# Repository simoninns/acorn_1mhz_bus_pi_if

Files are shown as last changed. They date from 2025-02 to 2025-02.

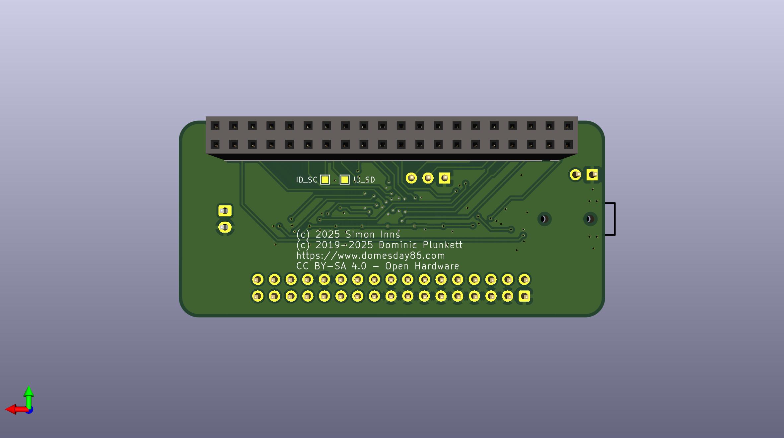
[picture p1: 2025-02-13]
docs/Acorn_1Mhz_bus_PiZero_interface_back.jpg

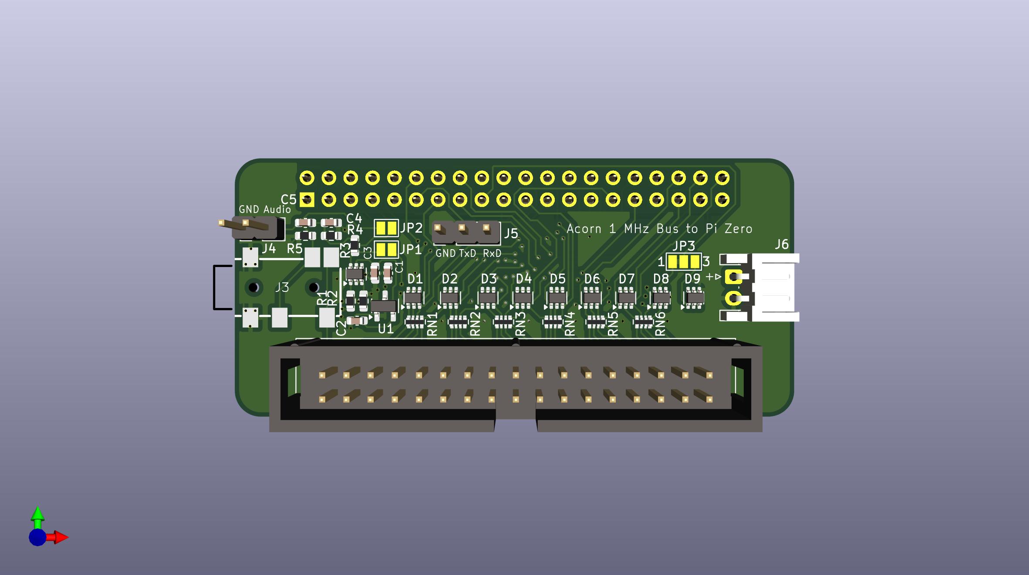
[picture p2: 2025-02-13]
docs/Acorn_1Mhz_bus_PiZero_interface_front.jpg

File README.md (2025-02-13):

# Overview
This project provides a Pi Zero hat which allows a Raspberry Pi to be connected to a BBC Micro or Master via the 1 MHz bus port.  The hat is compatible with all versions of the Raspberry Pi (with 40 pin GPIO headers)

Since the BBC Micro is 5Vs and the Pi is 3.3Vs bi-directional level shifting is required.  In addition, the board provides an active audio buffer to allow the Pi Zero to output audio via the GPIO header.  Audio is routed into the BBC Micro if the audio jack isn't required.

# Production
Production files for JLCPCB.com are included for both the PCB and component assembly.  A custom DRC is also included that checks the project files against JLC's production rules.  Production files can be found in the repo:

https://github.com/simoninns/acorn_1mhz_bus_pi_if/tree/main/kicad/jlcpcb

# Use with Raspberry Pi 3B+
Some Raspberry Pi models will not boot due to leakage on the 3.3V rails - the project provides a jumper that can be set if you want to use on of the affected models.  JP3 pins 1 to 2 should be cut and a solder blob placed on 2-3.  Please see the schematic for details.

# Removal of active audio
To lower production cost the on-board LDO and buffer ICs can be omitted (as well as the audio jack).  Bridging JP1 and JP2 will bypass the active components and provide only a passive audio filter (this works fine but provides a poorer sound quality).

## Project status
This project is at first release.  Please read the wiki and see YouTube for consruction videos (detailed in the wiki also).

## Author
This project is designed and maintained by Simon Inns with help from Dominic Plunkett and Daniel Jameson.

## Software License (GPLv3)

    This is free software: you can redistribute it and/or modify
    it under the terms of the GNU General Public License as published by
    the Free Software Foundation, either version 3 of the License, or
    (at your option) any later version.

    Valiant Turtle 2 is distributed in the hope that it will be useful,
    but WITHOUT ANY WARRANTY; without even the implied warranty of
    MERCHANTABILITY or FITNESS FOR A PARTICULAR PURPOSE.  See the
    GNU General Public License for more details.

    You should have received a copy of the GNU General Public License
    along with this program.  If not, see <http://www.gnu.org/licenses/>.

## Hardware License (Creative Commons BY-SA 4.0)
Please see the following link for details: https://creativecommons.org/licenses/by-sa/4.0/

You are free to:

Share - copy and redistribute the material in any medium or format
Adapt - remix, transform, and build upon the material
for any purpose, even commercially.

This license is acceptable for Free Cultural Works.

The licensor cannot revoke these freedoms as long as you follow the license terms.

Under the following terms:

Attribution - You must give appropriate credit, provide a link to the license, and indicate if changes were made. You may do so in any reasonable manner, but not in any way that suggests the licensor endorses you or your use.

ShareAlike - If you remix, transform, or build upon the material, you must distribute your contributions under the same license as the original.

No additional restrictions - You may not apply legal terms or technological measures that legally restrict others from doing anything the license permits.

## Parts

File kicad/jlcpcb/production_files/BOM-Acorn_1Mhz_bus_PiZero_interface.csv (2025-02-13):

Comment | Designator | Footprint | LCSC | Quantity
100R | R1,R4 | R_0603_1608Metric | C105588 | 2
220R | R3 | R_0603_1608Metric | C107696 | 1
470R | R2 | R_0603_1608Metric | C114433 | 1
47uF | C5 | C_0603_1608Metric | C140782 | 1
1K8 | R5 | R_0603_1608Metric | C144686 | 1
100nF | C3,C4 | C_0603_1608Metric | C14663 | 2
MMBD4148TW | D1,D2,D3,D4,D5,D6,D7,D8,D9 | SOT-363_SC-70-6 | C157538 | 9
1uF | C1,C2 | C_0603_1608Metric | C15849 | 2
1MHz Bus | J1 | IDC-Header_2x17_P2.54mm_Vertical | C20920 | 1
Audio_Jack_3420 | J3 | PJ-3420-X-SMT | C319102 | 1
100R | RN1,RN2,RN3,RN4,RN5,RN6 | R_Array_Convex_4x0402 | C326873 | 6
Power In | J6 | JST_EH_S2B-EH_1x02_P2.50mm_Horizontal | C514173 | 1
NC7WZ16 | U2 | SOT-363_SC-70-6 | C5207819 | 1
XC6206P332MR | U1 | SOT-23-3 | C5446 | 1

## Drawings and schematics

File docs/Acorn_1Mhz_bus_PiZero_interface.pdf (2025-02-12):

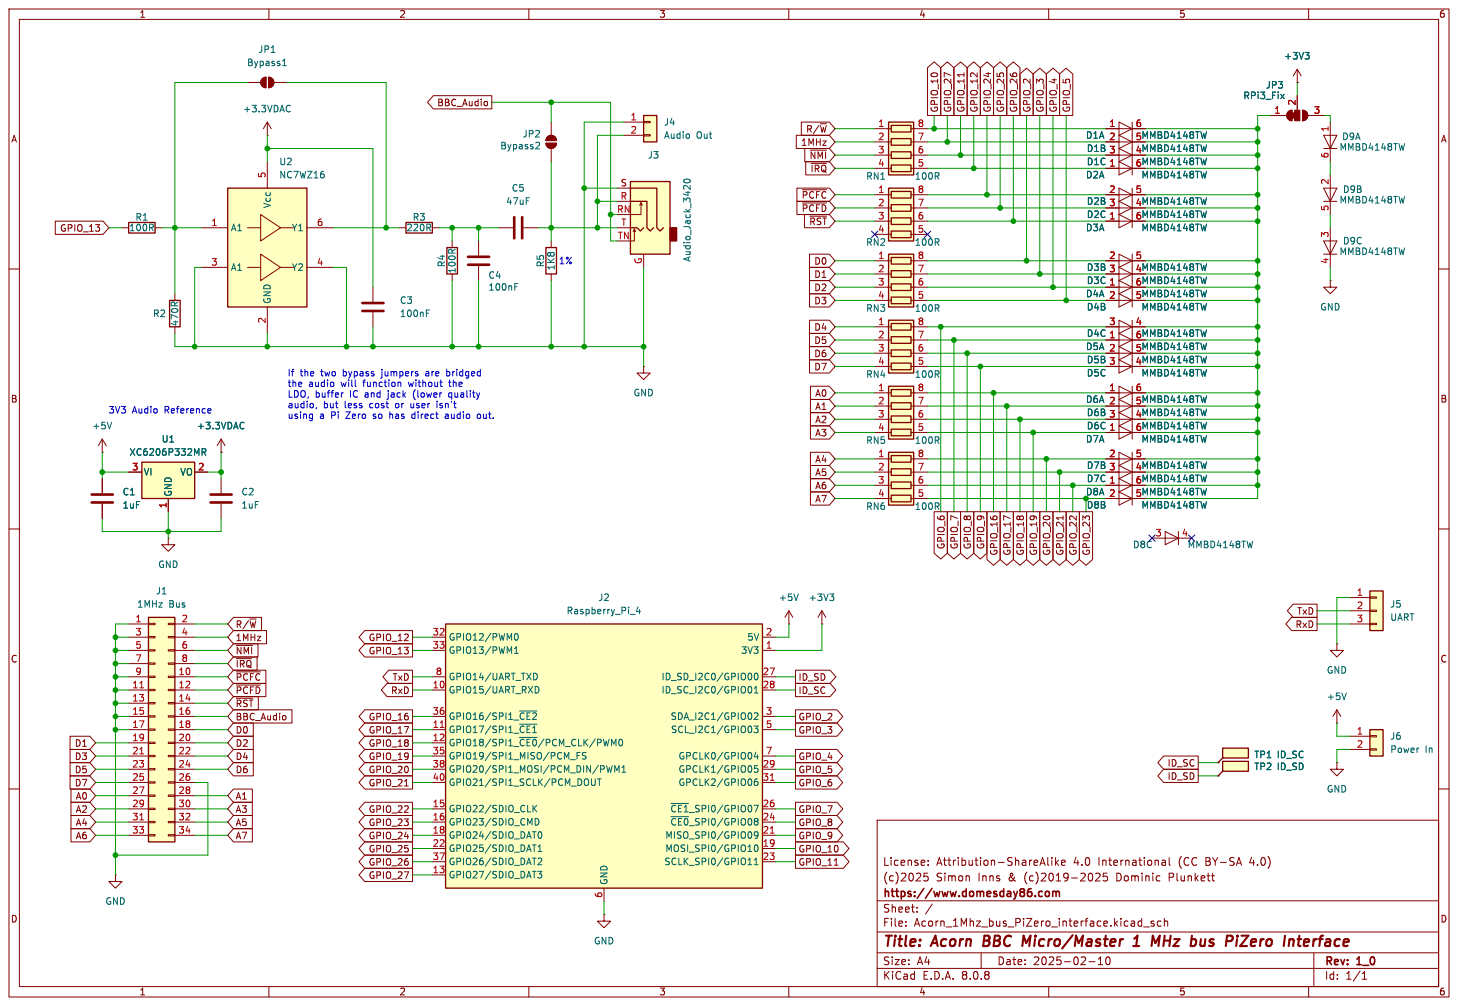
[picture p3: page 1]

If the two bypass jumpers are bridged

File: Acorn_1Mhz_bus_PiZero_interface.kicad_sch Sheet: / https://www.domesday86.com

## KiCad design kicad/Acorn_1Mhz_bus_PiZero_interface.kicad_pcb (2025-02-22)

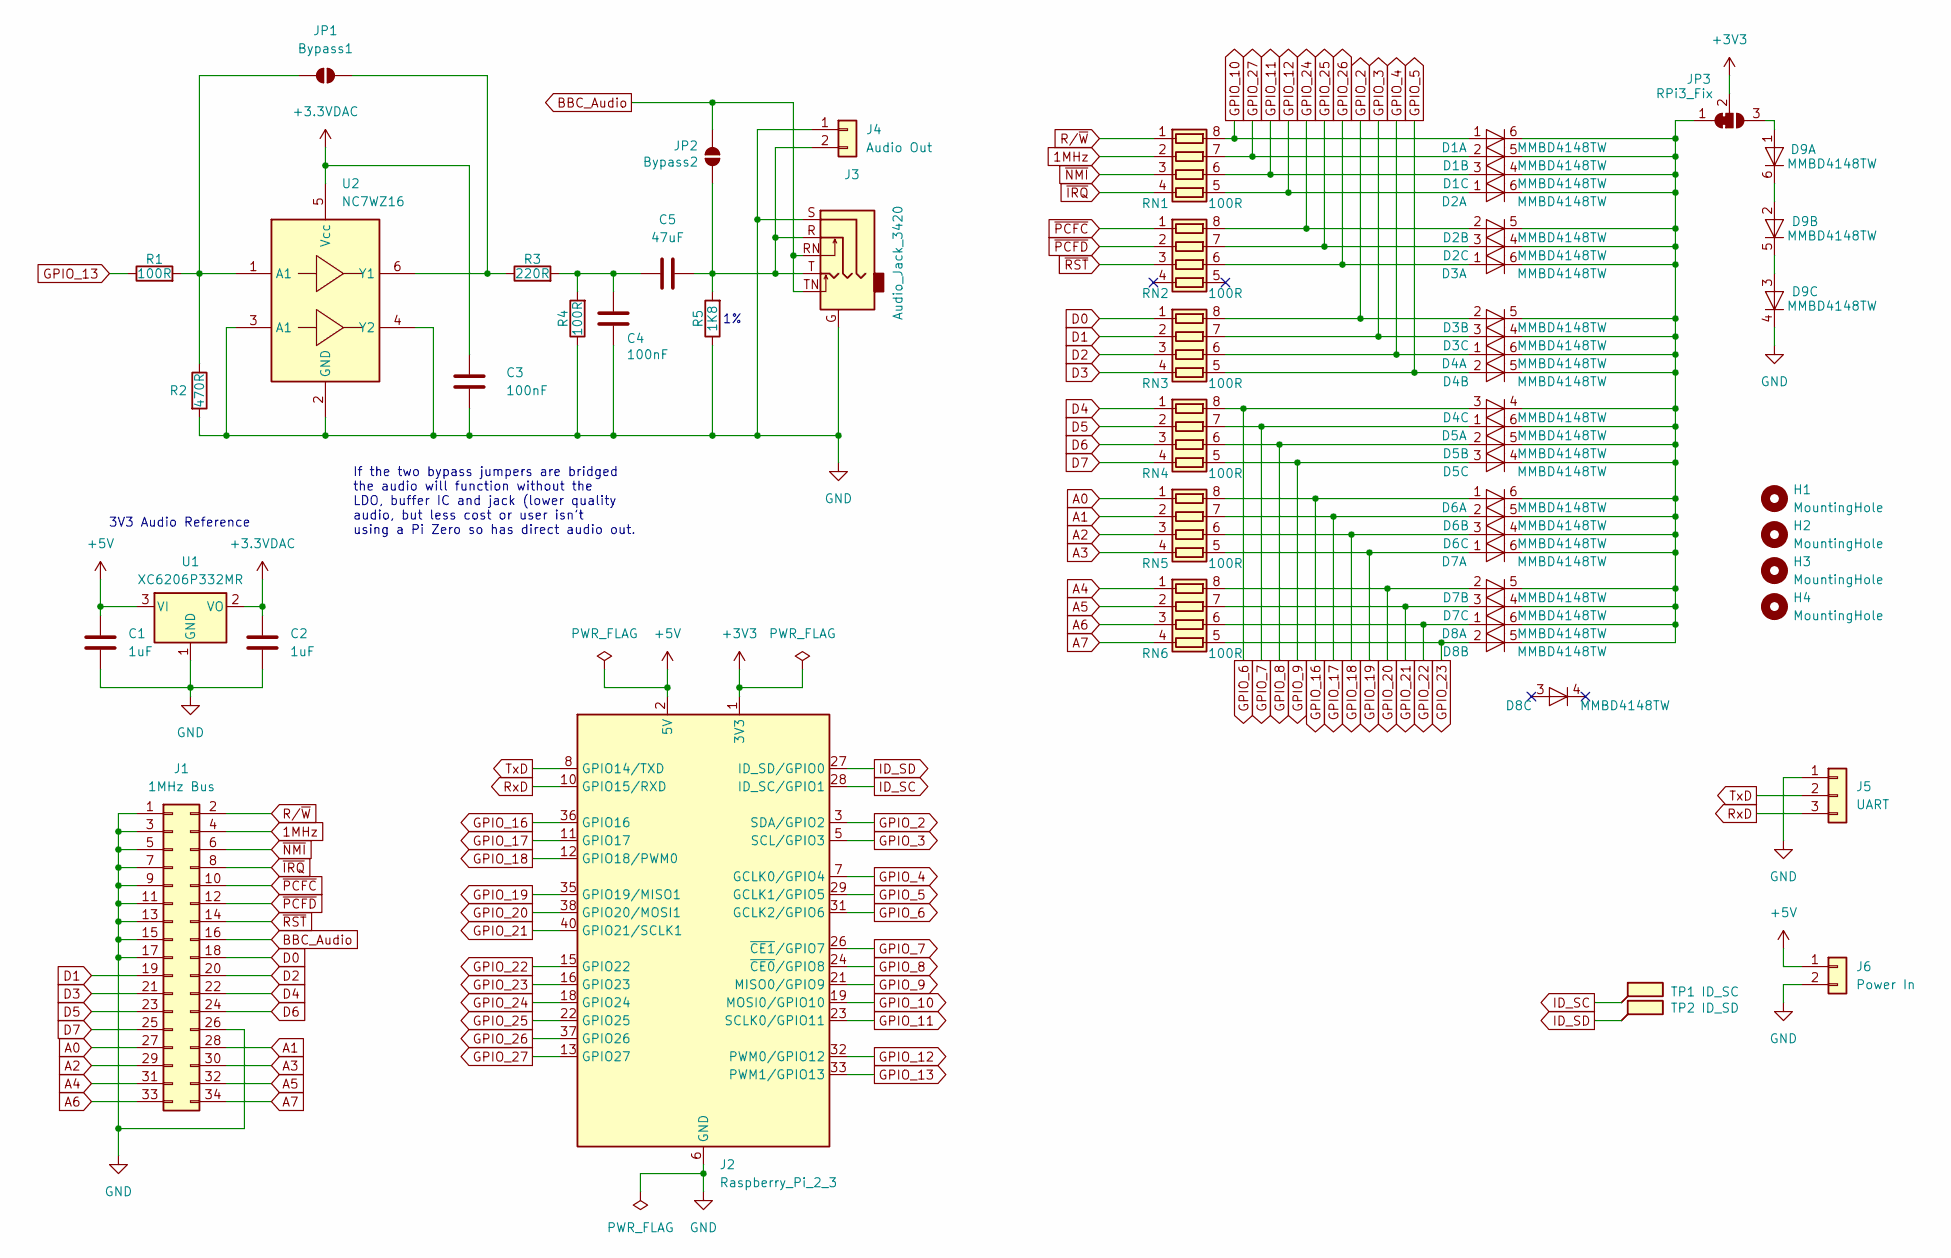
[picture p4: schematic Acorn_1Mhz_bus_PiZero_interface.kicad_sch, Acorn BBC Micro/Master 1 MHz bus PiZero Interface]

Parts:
C1, C2: 1uF; C_0603_1608Metric; LCSC C15849
C3, C4: 100nF; C_0603_1608Metric; LCSC C14663
C5: 47uF; C_0603_1608Metric; LCSC C140782
D1, D2, D3, D4, D5, D6, D7, D8, D9: MMBD4148TW; SOT-363_SC-70-6; LCSC C157538
H1, H2, H3, H4: MountingHole; MountingHole_2.7mm_M2.5_DIN965
J1: 1MHz Bus; IDC-Header_2x17_P2.54mm_Vertical; LCSC C20920
J2: Raspberry_Pi_2_3; PinSocket_2x20_P2.54mm_Vertical
J3: Audio_Jack_3420; PJ-3420-X-SMT; LCSC C319102
J4: Audio Out; PinHeader_1x02_P2.54mm_Vertical
J5: UART; PinHeader_1x03_P2.54mm_Vertical
J6: Power In; JST_EH_S2B-EH_1x02_P2.50mm_Horizontal; LCSC C514173
JP1: Bypass1; SolderJumper-2_P1.3mm_Open_Pad1.0x1.5mm
JP2: Bypass2; SolderJumper-2_P1.3mm_Open_Pad1.0x1.5mm
JP3: RPi3_Fix; SolderJumper-3_P1.3mm_Bridged12_Pad1.0x1.5mm_NumberLabels
R1, R4: 100R; R_0603_1608Metric; LCSC C105588
R2: 470R; R_0603_1608Metric; LCSC C114433
R3: 220R; R_0603_1608Metric; LCSC C107696
R5: 1K8; R_0603_1608Metric; LCSC C113298
RN1, RN2, RN3, RN4, RN5, RN6: 100R; R_Array_Convex_4x0402; LCSC C326873
TP1: ID_SC; TestPoint_Pad_1.0x1.0mm
TP2: ID_SD; TestPoint_Pad_1.0x1.0mm
U1: XC6206P332MR; SOT-23-3; LCSC C5446
U2: NC7WZ16; SOT-363_SC-70-6; LCSC C5207819

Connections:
1MHz: J1.4, RN1.2 (R2.1)
+3.3VDAC: C2.1, C3.1, U1.2 (VO), U2.5 (Vcc)
+3V3: J2.1 (3V3), J2.17 (3V3), JP3.2 (C)
+5V: C1.1, J2.2 (5V), J2.4 (5V), J6.1, U1.3 (VI)
A0: J1.27, RN5.1 (R1.1)
A1: J1.28, RN5.2 (R2.1)
A2: J1.29, RN5.3 (R3.1)
A3: J1.30, RN5.4 (R4.1)
A4: J1.31, RN6.1 (R1.1)
A5: J1.32, RN6.2 (R2.1)
A6: J1.33, RN6.3 (R3.1)
A7: J1.34, RN6.4 (R4.1)
BBC_Audio: J1.16, J3.RN, J3.TN, JP2.2 (B)
D0: J1.18, RN3.1 (R1.1)
D1: J1.19, RN3.2 (R2.1)
D2: J1.20, RN3.3 (R3.1)
D3: J1.21, RN3.4 (R4.1)
D4: J1.22, RN4.1 (R1.1)
D5: J1.23, RN4.2 (R2.1)
D6: J1.24, RN4.3 (R3.1)
D7: J1.25, RN4.4 (R4.1)
GND: C1.2, C2.2, C3.2, C4.2, D9.4 (K), J1.1, J1.3, J1.5, J1.7, J1.9, J1.11, J1.13, J1.15, J1.17, J1.26, J2.6 (GND), J2.9 (GND), J2.14 (GND), J2.20 (GND), J2.25 (GND), J2.30 (GND), J2.34 (GND), J2.39 (GND), J3.G, J3.S, J4.1, J5.1, J6.2, R2.2, R4.1, R5.1, U1.1 (GND), U2.2 (GND), U2.3 (A1), U2.4 (Y2)
GPIO_2: D3.2 (A), J2.3 (SDA/GPIO2), RN3.8 (R1.2)
GPIO_3: D3.3 (A), J2.5 (SCL/GPIO3), RN3.7 (R2.2)
GPIO_4: D4.1 (A), J2.7 (GCLK0/GPIO4), RN3.6 (R3.2)
GPIO_5: D4.2 (A), J2.29 (GCLK1/GPIO5), RN3.5 (R4.2)
GPIO_6: D4.3 (A), J2.31 (GCLK2/GPIO6), RN4.8 (R1.2)
GPIO_7: D5.1 (A), J2.26 (~CE1/GPIO7), RN4.7 (R2.2)
GPIO_8: D5.2 (A), J2.24 (~CE0/GPIO8), RN4.6 (R3.2)
GPIO_9: D5.3 (A), J2.21 (MISO0/GPIO9), RN4.5 (R4.2)
GPIO_10: D1.1 (A), J2.19 (MOSI0/GPIO10), RN1.8 (R1.2)
GPIO_11: D1.3 (A), J2.23 (SCLK0/GPIO11), RN1.6 (R3.2)
GPIO_12: D2.1 (A), J2.32 (PWM0/GPIO12), RN1.5 (R4.2)
GPIO_13: J2.33 (PWM1/GPIO13), R1.1
GPIO_16: D6.1 (A), J2.36 (GPIO16), RN5.8 (R1.2)
GPIO_17: D6.2 (A), J2.11 (GPIO17), RN5.7 (R2.2)
GPIO_18: D6.3 (A), J2.12 (GPIO18/PWM0), RN5.6 (R3.2)
GPIO_19: D7.1 (A), J2.35 (GPIO19/MISO1), RN5.5 (R4.2)
GPIO_20: D7.2 (A), J2.38 (GPIO20/MOSI1), RN6.8 (R1.2)
GPIO_21: D7.3 (A), J2.40 (GPIO21/SCLK1), RN6.7 (R2.2)
GPIO_22: D8.1 (A), J2.15 (GPIO22), RN6.6 (R3.2)
GPIO_23: D8.2 (A), J2.16 (GPIO23), RN6.5 (R4.2)
GPIO_24: D2.2 (A), J2.18 (GPIO24), RN2.8 (R1.2)
GPIO_25: D2.3 (A), J2.22 (GPIO25), RN2.7 (R2.2)
GPIO_26: D3.1 (A), J2.37 (GPIO26), RN2.6 (R3.2)
GPIO_27: D1.2 (A), J2.13 (GPIO27), RN1.7 (R2.2)
ID_SC: J2.28 (ID_SC/GPIO1), TP1.1
ID_SD: J2.27 (ID_SD/GPIO0), TP2.1
unnamed: C4.1, C5.1, R3.2, R4.2
unnamed: D1.4 (K), D1.5 (K), D1.6 (K), D2.4 (K), D2.5 (K), D2.6 (K), D3.4 (K), D3.5 (K), D3.6 (K), D4.4 (K), D4.5 (K), D4.6 (K), D5.4 (K), D5.5 (K), D5.6 (K), D6.4 (K), D6.5 (K), D6.6 (K), D7.4 (K), D7.5 (K), D7.6 (K), D8.5 (K), D8.6 (K), JP3.1 (A)
unnamed: D9.1 (A), JP3.3 (B)
unnamed: D9.2 (A), D9.6 (K)
unnamed: D9.3 (A), D9.5 (K)
unnamed: C5.2, J3.R, J3.T, J4.2, JP2.1 (A), R5.2
unnamed: JP1.1 (A), R1.2, R2.1, U2.1 (A1)
unnamed: JP1.2 (B), R3.1, U2.6 (Y1)
RxD: J2.10 (GPIO15/RXD), J5.3
R/~W: J1.2, RN1.1 (R1.1)
TxD: J2.8 (GPIO14/TXD), J5.2
~IRQ: J1.8, RN1.4 (R4.1)
~NMI: J1.6, RN1.3 (R3.1)
~PCFC: J1.10, RN2.1 (R1.1)
~PCFD: J1.12, RN2.2 (R2.1)
~RST: J1.14, RN2.3 (R3.1)

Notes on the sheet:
If the two bypass jumpers are bridged the audio will function without the LDO, buffer IC and jack (lower quality audio, but less cost or user isn't using a Pi Zero so has direct audio out.
3V3 Audio Reference

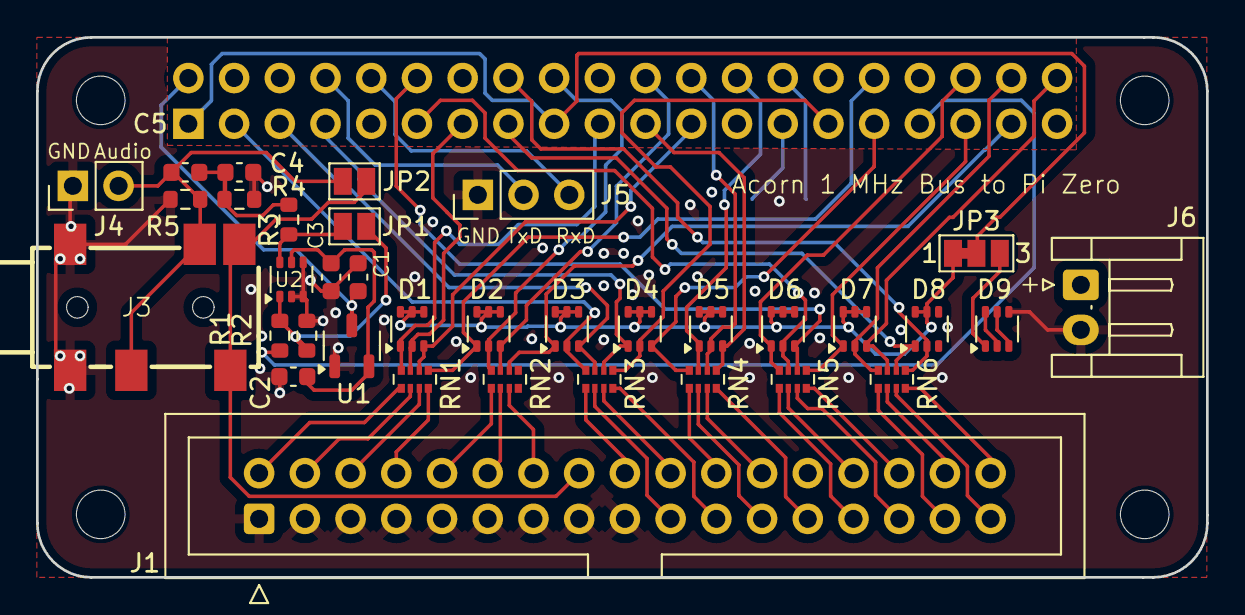
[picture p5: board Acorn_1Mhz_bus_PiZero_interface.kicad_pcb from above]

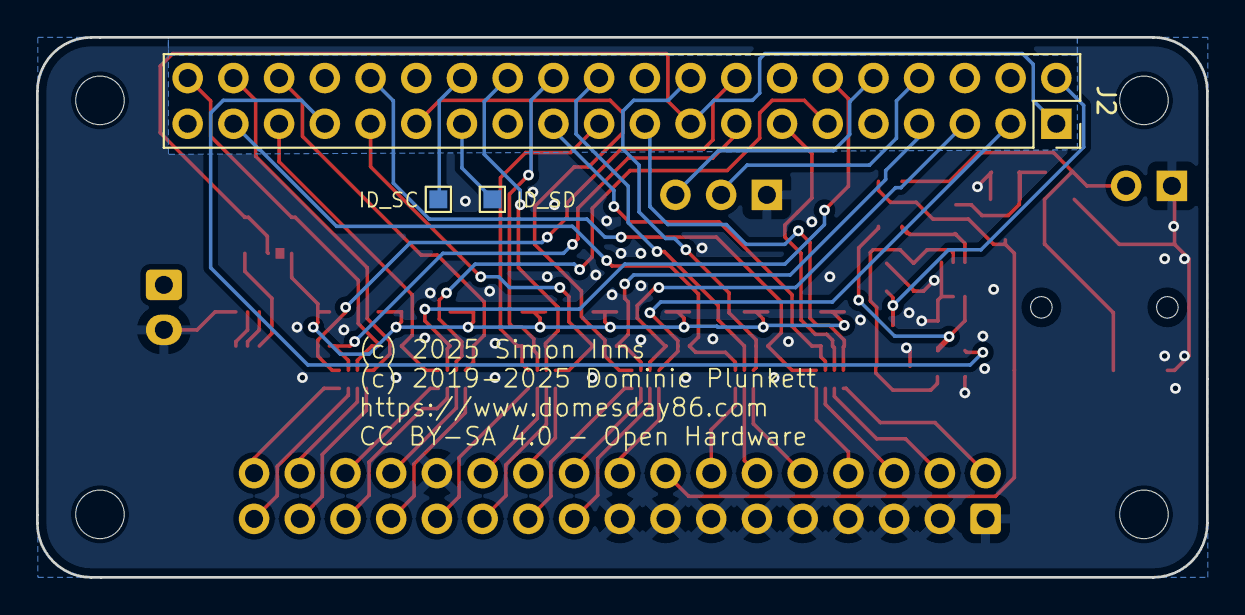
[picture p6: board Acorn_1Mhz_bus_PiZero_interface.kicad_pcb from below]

Board: 4 copper layers, 65.0 x 30.0 mm, 42 parts (3 on the bottom side), 64 nets.

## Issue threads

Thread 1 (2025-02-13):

Missing mounting holes in JLCPCB gerber images

simoninns, 2025-02-13:
In the gerber rendering on JLCPCB it looks like there are no mounting holes even though they were marked on the PCB.  It probably needs M2.5 mounting holes added to both the schematic and PCB files explicitly to ensure the finished board gets them.

This is not a big enough issue to prevent pre-release testing, so I'm raising this issue as a reminder to fix this before release.

simoninns, 2025-02-22:
Fixed in latest commit

Closed 2025-02-22.

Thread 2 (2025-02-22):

Internal speaker volume is low

simoninns, 2025-02-22:
The internal speaker volume is a little quiet due to the fact that the filter design is from the official Raspberry Pi schematics and only really suitable for the 3.5mm jack output.  It's probably not a really big issue since the internal speaker of the BBC Master is terrible quality anyway - but I'm raising this issue just to make a note.

The best way to solve it would probably be to add a small pre-amp on the audio output to the 1MHz bus connector.

simoninns, 2025-02-23:
I tested the amplitude of the audio output from the 3.5mm jack of a Pi 3B+ for comparison.  As expected, the amplitude of the level-shifter is the same (which it should be since it mirrors the audio buffer of the Pi).  So this issues is an enhancement rather than a bug-fix (and probably not worth solving).

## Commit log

2025-02-10 Basic KiCAD project with partial schematic - checking in before added Pi Zero sub-module
    [Acorn_1Mhz_bus_PiZero_interface.kicad_pcb, Acorn_1Mhz_bus_PiZero_interface.kicad_sch]
2025-02-10 Completed schematic ready for verification
    [Acorn_1Mhz_bus_PiZero_interface.kicad_sch]
2025-02-11 Completed schematic and added board file. Basic positioning is done but no routing.
    [Acorn_1Mhz_bus_PiZero_interface.kicad_pcb, Acorn_1Mhz_bus_PiZero_interface.kicad_sch]
2025-02-11 Got board outline and position of all components. Routing still missing.
    [Acorn_1Mhz_bus_PiZero_interface.kicad_pcb, Acorn_1Mhz_bus_PiZero_interface.kicad_sch]
2025-02-11 All PCB routing complete - just needs some copper fill
    [Acorn_1Mhz_bus_PiZero_interface.kicad_pcb]
2025-02-11 Flooded and ready for gerber generation - added renderings of front and back of PCB to docs
    [Acorn_1Mhz_bus_PiZero_interface.kicad_pcb]
2025-02-11 Changed board dimensions and redid the routing
    [Acorn_1Mhz_bus_PiZero_interface.kicad_pcb]
2025-02-11 Fixed some DRC warnings around silkscreen text sizes
    [Acorn_1Mhz_bus_PiZero_interface.kicad_pcb]
2025-02-11 Reversed polarity of the power connector. Added BoM spreadsheet with JLCPCB part numbers for assembly
    [Acorn_1Mhz_bus_PiZero_interface.kicad_pcb, Acorn_1Mhz_bus_PiZero_interface.kicad_sch, JLCPCB_BoM.ods]
2025-02-12 Added audio in/out test pads
    [Acorn_1Mhz_bus_PiZero_interface.kicad_pcb, Acorn_1Mhz_bus_PiZero_interface.kicad_sch]
2025-02-12 New schematic design with active audio buffering - schematic not updated
    [Acorn_1Mhz_bus_PiZero_interface.kicad_sch]
2025-02-12 New design for audio - added footprints (including SMD audio jack)
    [Acorn_1Mhz_bus_PiZero_interface.kicad_pcb, Acorn_1Mhz_bus_PiZero_interface.kicad_sch]
2025-02-12 Basic layout complete needs routing
    [Acorn_1Mhz_bus_PiZero_interface.kicad_pcb, Acorn_1Mhz_bus_PiZero_interface.kicad_sch]
2025-02-12 Finished PCB routing a silkscreen - need to track some DRC errors regarding footprints
    [Acorn_1Mhz_bus_PiZero_interface.kicad_pcb]
2025-02-12 DRC issues solved, copper fills completed. Ready for review.
    [Acorn_1Mhz_bus_PiZero_interface.kicad_pcb]
2025-02-12 Added production files for JLCPCB including gerbers and BoM for PCBA service
    [Acorn_1Mhz_bus_PiZero_interface-CuBottom.gbr, Acorn_1Mhz_bus_PiZero_interface-CuIn1.gbr, Acorn_1Mhz_bus_PiZero_interface-CuIn2.gbr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]
2025-02-12 tweaked routing to improve ground plane
    [Acorn_1Mhz_bus_PiZero_interface.kicad_pcb]
2025-02-13 Fixed small DRC error, produced production files for JLCPCB and verified component placement and rotations. Ready for production.
    [Acorn_1Mhz_bus_PiZero_interface-CuBottom.gbr, Acorn_1Mhz_bus_PiZero_interface-CuIn1.gbr, Acorn_1Mhz_bus_PiZero_interface-CuIn2.gbr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]
2025-02-13 Added JLCPCB custom DRC file and corrected PCB against it. Updated README
    [Acorn_1Mhz_bus_PiZero_interface.kicad_pcb]
2025-02-13 Board was rejected due to incorrect 0603x4 RN1-6 parts... this should have been 0402x6. Also the 1K8 resistor was 5% and should be 1%.
    [Acorn_1Mhz_bus_PiZero_interface-CuBottom.gbr, Acorn_1Mhz_bus_PiZero_interface-CuIn1.gbr, Acorn_1Mhz_bus_PiZero_interface-CuIn2.gbr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]
2025-02-22 Updated Raspi symbol to use kicad standard library. Added missing mounting holes to schematic. Updated footprints and pulled changes into PCB layout. Aligned M2.5 mounting holes with standard HAT des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
    [Acorn_1Mhz_bus_PiZero_interface.kicad_pcb, Acorn_1Mhz_bus_PiZero_interface.kicad_sch]
2025-02-22 Updated JLCPCB production files ready for release
    [Acorn_1Mhz_bus_PiZero_interface-CuBottom.gbr, Acorn_1Mhz_bus_PiZero_interface-CuIn1.gbr, Acorn_1Mhz_bus_PiZero_interface-CuIn2.gbr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]

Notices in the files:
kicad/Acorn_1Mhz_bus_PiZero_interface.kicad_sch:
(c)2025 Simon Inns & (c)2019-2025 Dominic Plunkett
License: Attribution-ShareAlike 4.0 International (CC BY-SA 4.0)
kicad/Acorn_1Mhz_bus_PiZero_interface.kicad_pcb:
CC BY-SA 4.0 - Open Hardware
